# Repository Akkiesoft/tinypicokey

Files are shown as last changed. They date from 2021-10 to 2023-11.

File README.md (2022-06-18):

# TinyPicoKey

[Pimoroni Tiny 2040](https://shop.pimoroni.com/products/tiny-2040)に組み合わせて使用できる1キーだけのキーボード用基板です。Tiny 2040のGP6に接続されています。

## 制作環境

KiCad (6.0)

## ボード

### TinyPicoKey

Cherry MXおよび互換キースイッチ用ボードです

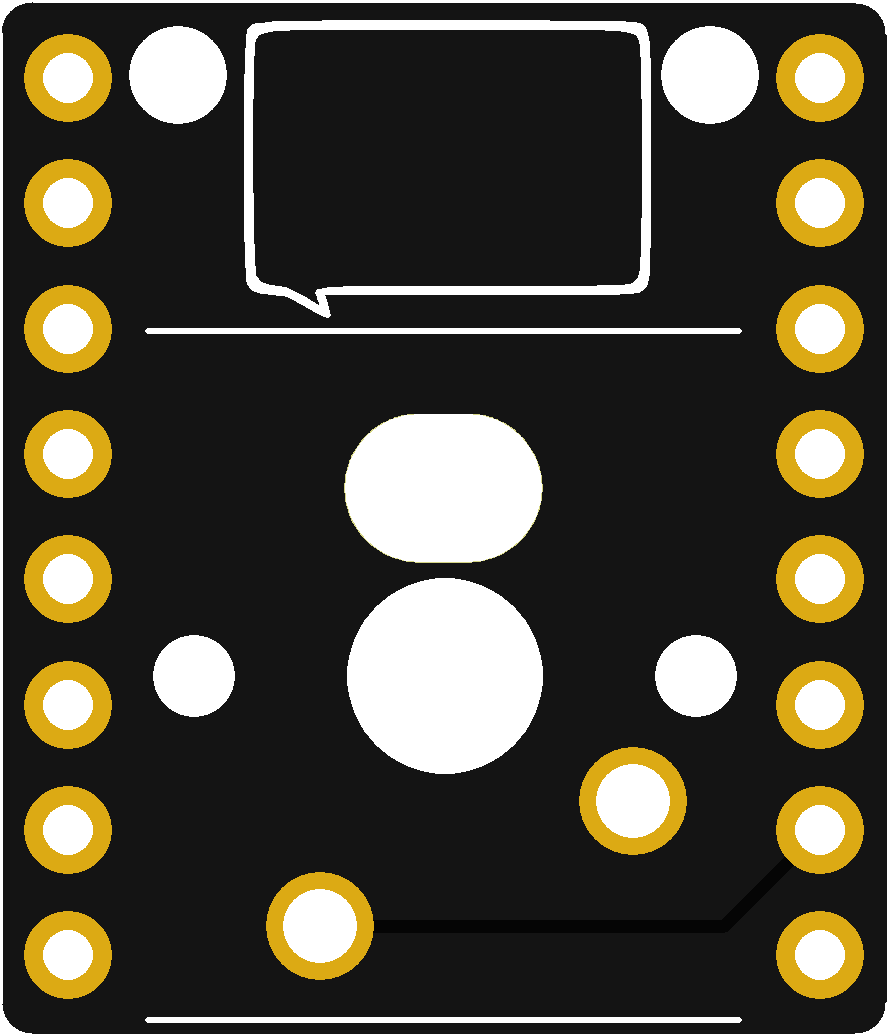
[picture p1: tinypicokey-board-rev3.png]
board


### TinyPicoKey-LP

Kailhロープロファイルスイッチ（PG1350）用ボードです

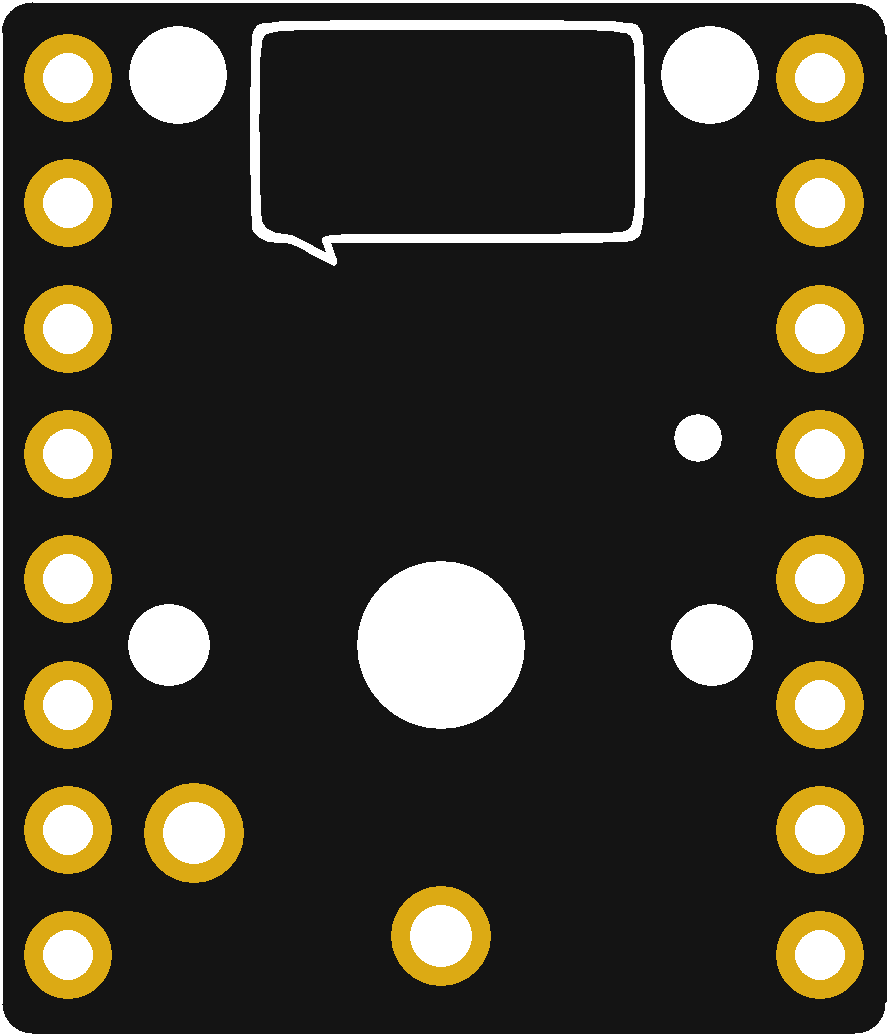
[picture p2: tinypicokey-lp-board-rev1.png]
board-lp


### TinyPicoTrio

TinyPicoKeyを3つ搭載できるボードです。TinyPicoKeyは上下逆に取り付けても動作します。左からGP4、GP5、GP6に接続されていて、右のキーはTinyPicoKey単体で使用する場合と共用です。

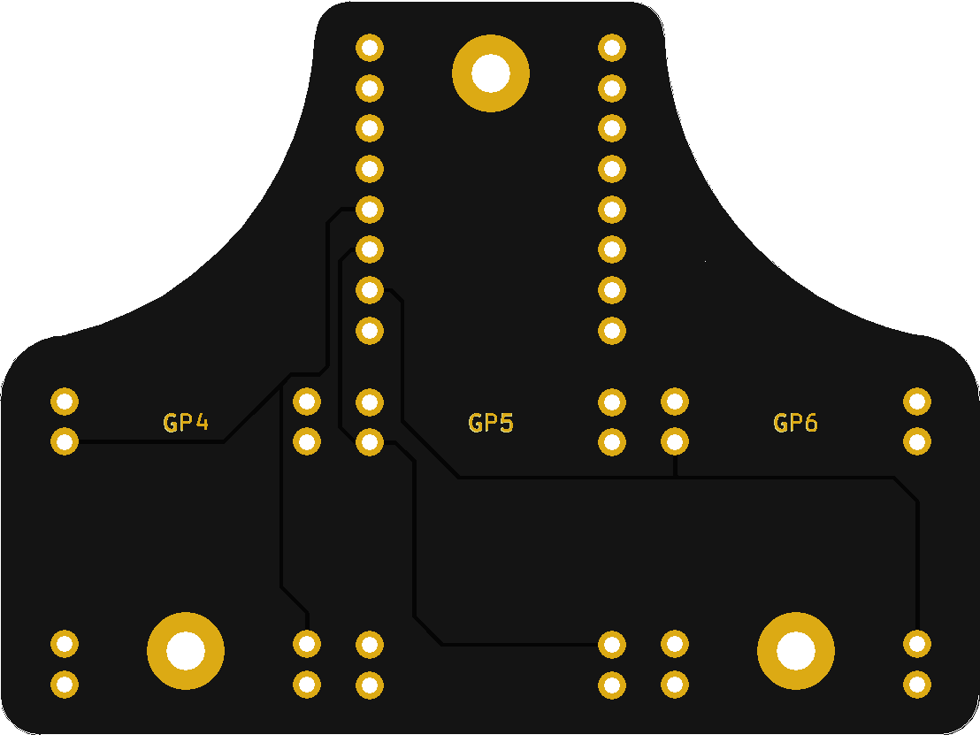
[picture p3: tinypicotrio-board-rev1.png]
board-trio


## 組み立て例

ピンヘッダ/ピンソケットは以下のパーツがおすすめです。

* [ロープロファイルピンヘッダ 7.7mm（低オス） 1x40（40P）](https://akizukidenshi.com/catalog/g/gC-02900/)
* [シングルピンソケット （低メス） 1x20 （20P）](https://akizukidenshi.com/catalog/g/gC-03138/)

TinyPicoKeyにピンヘッダを、Tiny 2040にピンソケットをはんだ付けすることをおすすめします。

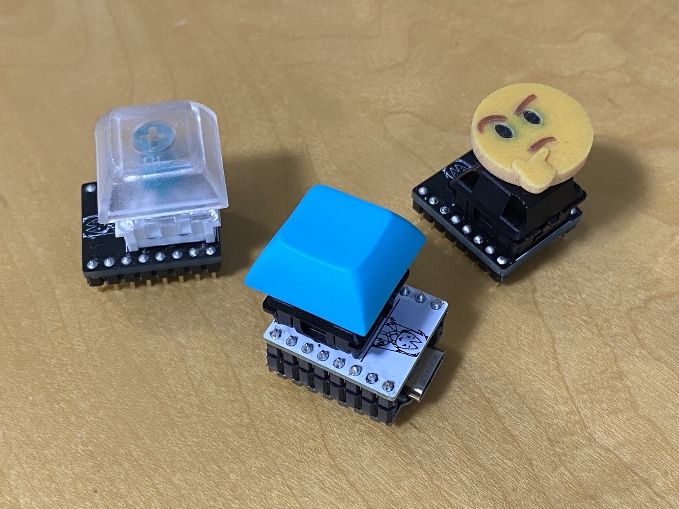
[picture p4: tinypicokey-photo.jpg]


## サンプルスクリプト

CircuitPythonで使うサンプルです。

## License

board-tinypicokey-lp/Library.pretty/SW_PG1350.kicad_mod from [daprice/keyswitches.pretty](https://github.com/daprice/keyswitches.pretty) is licensed under a [Creative Commons Attribution-ShareAlike 4.0 International License](https://creativecommons.org/licenses/by-sa/4.0/). We added a modification to remove the border line.

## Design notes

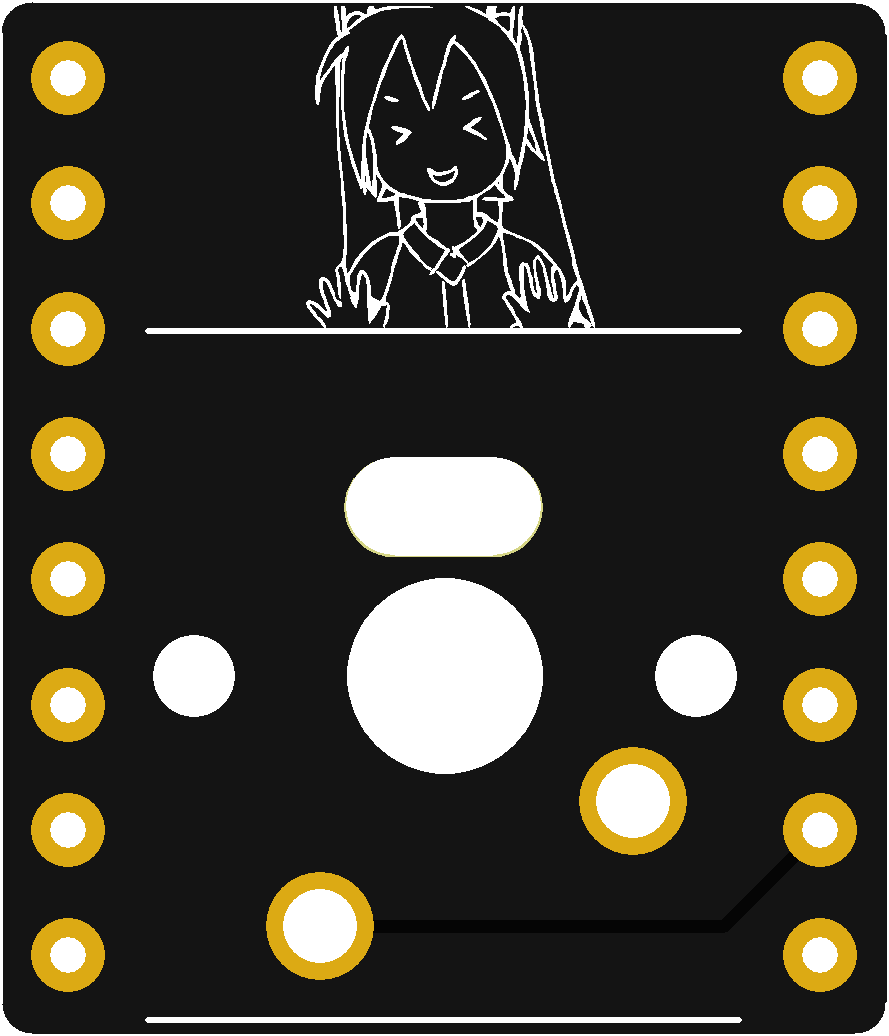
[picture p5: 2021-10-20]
tinypicokey-board.png

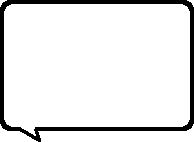
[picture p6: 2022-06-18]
board-tinypicokey/fukidashi/fukidashi.png

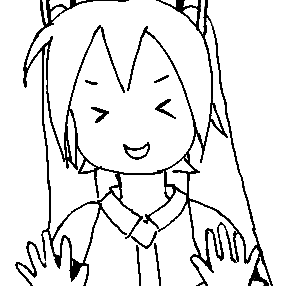
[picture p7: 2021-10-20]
board-tinypicokey/miku/miku.png

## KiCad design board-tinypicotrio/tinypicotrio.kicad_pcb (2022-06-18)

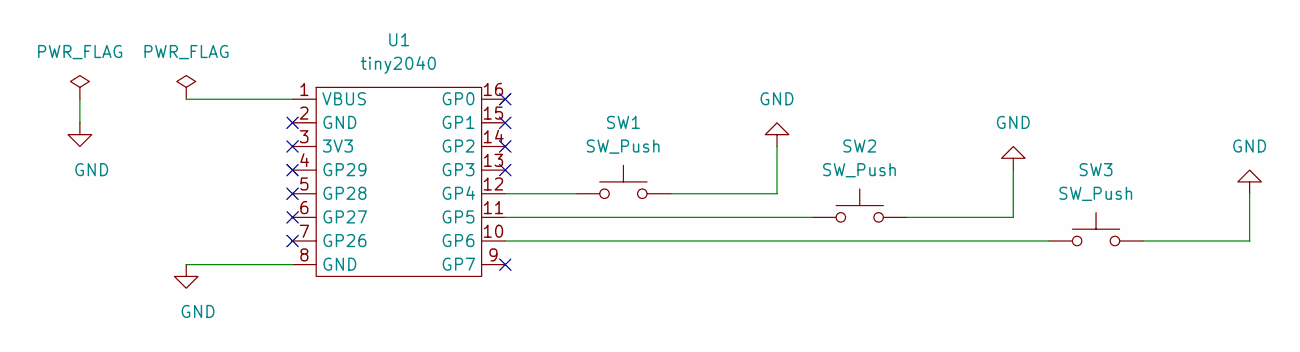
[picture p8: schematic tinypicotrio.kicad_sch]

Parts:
SW1, SW2, SW3: SW_Push; tinypicokey
U1: tiny2040; tiny2040_wo_debug

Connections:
GND: SW1.2, SW2.2, SW3.2, U1.8 (GND)
unnamed: SW1.1, U1.12 (GP4)
unnamed: SW2.1, U1.11 (GP5)
unnamed: SW3.1, U1.10 (GP6)

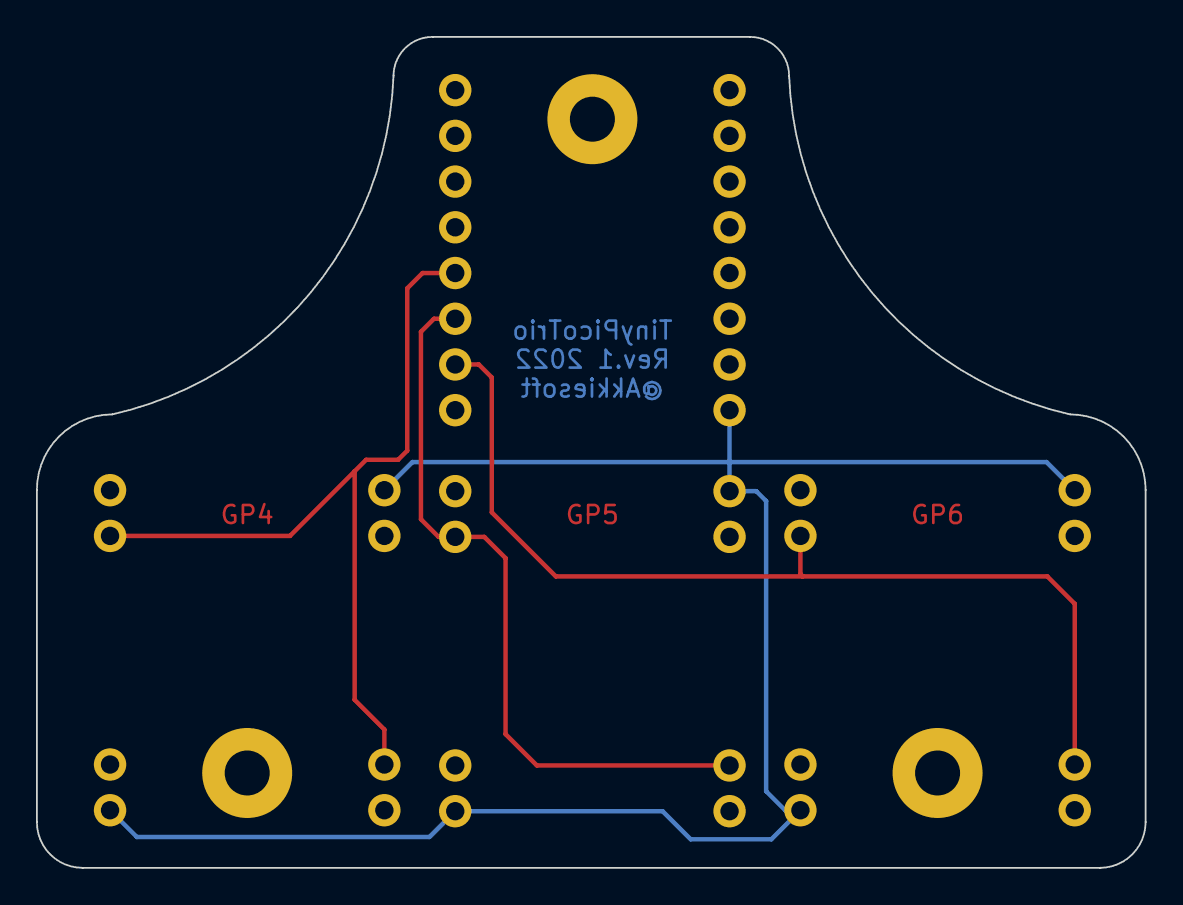
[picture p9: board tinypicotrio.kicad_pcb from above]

Board: 2 copper layers, 61.6 x 46.2 mm, 4 parts (1 on the bottom side), 4 nets.

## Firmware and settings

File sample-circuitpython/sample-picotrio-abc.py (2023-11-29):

# Written in CircuitPython
# for Raspberry Pi Pico or Pimoroni Tiny2040

import board
from digitalio import DigitalInOut, Direction, Pull
from time import sleep
import usb_hid
from adafruit_hid.keyboard import Keyboard
from adafruit_hid.keycode import Keycode
from adafruit_hid.keyboard_layout_us import KeyboardLayoutUS

led = (
    DigitalInOut(board.LED_R),
    DigitalInOut(board.LED_G),
    DigitalInOut(board.LED_B)
)
for l in led:
    l.direction = Direction.OUTPUT
    # tiny2040 LED is active low
    l.value = 1

keyboard = 0
while not keyboard:
    try:
        keyboard = Keyboard(usb_hid.devices)
        layout = KeyboardLayoutUS(keyboard)
    except:
        pass
    sleep(1)

keycodes = (
    ("Hello", Keycode.ENTER),
    (Keycode.A,),
    (Keycode.B,),
)
button = (
    DigitalInOut(board.GP4),
    DigitalInOut(board.GP5),
    DigitalInOut(board.GP6)
)
for b in button:
    b.switch_to_input(pull=Pull.UP)
sw = [0] * len(button)

def send_key(key):
    repeat_block = False
    try:
        for k in key:
            if (type(k) is str):
                repeat_block = True
                layout.write(k)
            else:
                keyboard.press(k)
            sleep(0.05)
        if repeat_block:
            keyboard.release_all()
    except:
        pass

while True:
    for i,b in enumerate(button):
        if not b.value:
            if not sw[i]:
                send_key(keycodes[i])
                sw[i] = 1
                led[i].value = 0
        else:
            if sw[i]:
                keyboard.release_all()
                sw[i] = 0
                for l in led:
                    l.value = 1

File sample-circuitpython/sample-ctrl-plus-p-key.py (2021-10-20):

# Written in CircuitPython
# for Raspberry Pi Pico or Pimoroni Tiny2040

import board
import digitalio
from time import sleep
import usb_hid
from adafruit_hid.keyboard import Keyboard
from adafruit_hid.keycode import Keycode

keyboard=Keyboard(usb_hid.devices)
keycodes = [Keycode.LEFT_CONTROL, Keycode.P]

button = digitalio.DigitalInOut(board.GP6)
button.switch_to_input(pull=digitalio.Pull.UP)

led_r = digitalio.DigitalInOut(board.LED_R)
led_r.direction = digitalio.Direction.OUTPUT
led_g = digitalio.DigitalInOut(board.LED_G)
led_g.direction = digitalio.Direction.OUTPUT
led_b = digitalio.DigitalInOut(board.LED_B)
led_b.direction = digitalio.Direction.OUTPUT
# tiny2040 LED is active low
led_r.value = 1
led_g.value = 1
led_b.value = 1

while True:
  if not button.value:
    led_g.value = 0
    led_b.value = 0
    for k in keycodes:
      keyboard.press(k)
      sleep(0.01)
  else:
    led_g.value = 1
    led_b.value = 1
    keyboard.release_all()
  sleep(0.02)

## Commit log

2021-11-13 Rev.2
    * resize through holes from 0.7mm to 1.02mm
    * add strap hole
    [tinypicokey-B_Cu.gbr, tinypicokey-B_Mask.gbr, tinypicokey-B_Paste.gbr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]
2022-06-18 Rev.3
    * expanded the strap hole
    * change board image
    [tinypicokey-B_Cu.gbr, tinypicokey-B_Mask.gbr, tinypicokey-B_Paste.gbr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]
2022-06-18 rename directory
    [tinypicokey-B_Cu.gbr, tinypicokey-B_Mask.gbr, tinypicokey-B_Paste.gbr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]
2022-06-18 Add TinyPicoKey-LP Rev.1
    [tinypicokey-lp-B_Cu.gbr, tinypicokey-lp-B_Mask.gbr, tinypicokey-lp-B_Paste.gbr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]
2022-06-18 Add TinyPicoTrio Rev.1
    [tinypicotrio-B_Cu.gbr, tinypicotrio-B_Mask.gbr, tinypicotrio-B_Paste.gbr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]
2023-08-14 add sample for picotrio
2023-11-29 update sample-picotrio-abc.py
    * replace some arrays with tuple
    * support to sending string
    * change the logic in main loop
    [sample-picotrio-abc.py]
